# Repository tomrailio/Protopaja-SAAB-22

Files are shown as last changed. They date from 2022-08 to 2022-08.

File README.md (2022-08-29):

# Protocamp-22 / SAAB handheld microwave transmitter.
Protopaja (Protocamp) is a 10 ECTS summerproject course in the University of Aalto to create 
functional interactive prototypes based on briefs by partnering companies. 
The School of Electrical Engineering is the organizational unit and the 
Teachers in charge: Salu Ylirisku and Kimmo Silvonen (kimmo.silvonen@aalto.fi)

SAAB recently developed the passive 'Sirius Compact' radar system for warfare. Now SAAB wants 
to develop a tool to test the limits and potential of the system. The Sirius Compact sensor 
network has been developed specifically with Electronic Warfare (EW) in mind. Modular as 
well as scalable, Sirius Compact's primary use case is seen as providing tactical-level 
situational awareness for warfare from battlefields by generating electromagnetic activity 
imaging with its sensors that detect electromagnetic radiation. In addition to this, Sirius 
Compact is also capable of predicting, classifying and prioritising radar and data link 
signals in the environment. SAAB needs a test tool for the radar system. The purpose of 
this project work is to create the desired test tool. 

The software will be published under a very permissive MIT license. See the licence file 
disclosed in this repository for further details.

# Schematics, PCB blueprint as well as part lists are located in Schematics folder

Technical Specifications:

  * Power level < 20 dBm EIRP (antenna gain + output power).

  * Frequency is 2.4 GHz.

  * Waveform: Continuous wave (narrow bandwidth).

  * Transmitter will be targeted manually by pointing.

Non-functional requirements:

  * Usability.

  * Reliability.

  * Performance.

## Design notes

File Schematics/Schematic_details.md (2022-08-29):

# This folder contains KiCad schematics and PCB blueprint files for our circuit

Components used for this circuit:
    - Antenna: Linx Technology ANT-W63-WRT-UFL
    - Synthesizer: Analog Devices ADF4350BCPZ-RL7
    - RF Amplifier: Analog Devices HMC589AST89E
    - Oscillator: Wurth Elektronik 831024807 (10 Mhz, used as Synthesizer reference)
    - Microcontroler: Atmega328P DIP-28N with a suitable 16Mhz crystal oscillator
    - Regulator: onsemi / Fairchild MC78L05ACP (5V output)
    - Regulator: Texas Instruments LP2992AIM5-3.3/NOPB (3.3V output)
    - Battery: LiPo battery with XT60 connector and voltage of 7.4V

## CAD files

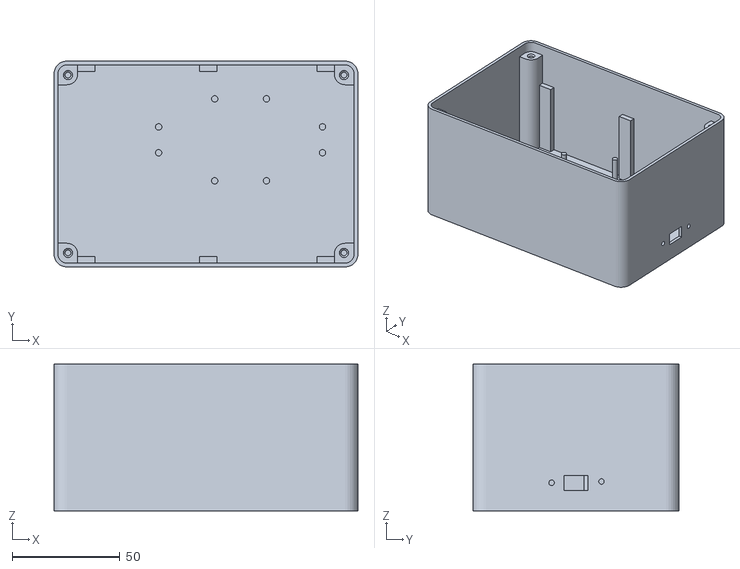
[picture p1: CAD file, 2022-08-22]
3D models/Case.stl
141.0 x 95.5 x 68.0

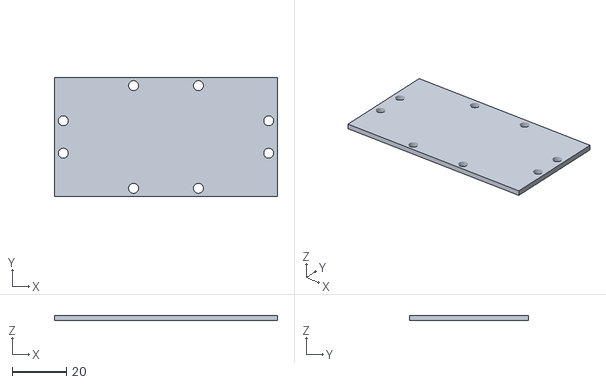
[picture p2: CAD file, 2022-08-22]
3D models/Battery_lid.stl
82.5 x 44.0 x 2.00

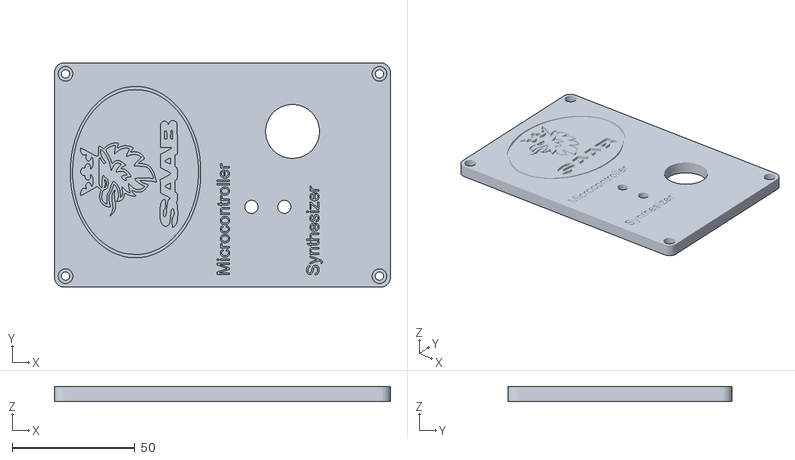
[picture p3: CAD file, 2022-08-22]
3D models/Lid.stl
137.0 x 91.5 x 6.00

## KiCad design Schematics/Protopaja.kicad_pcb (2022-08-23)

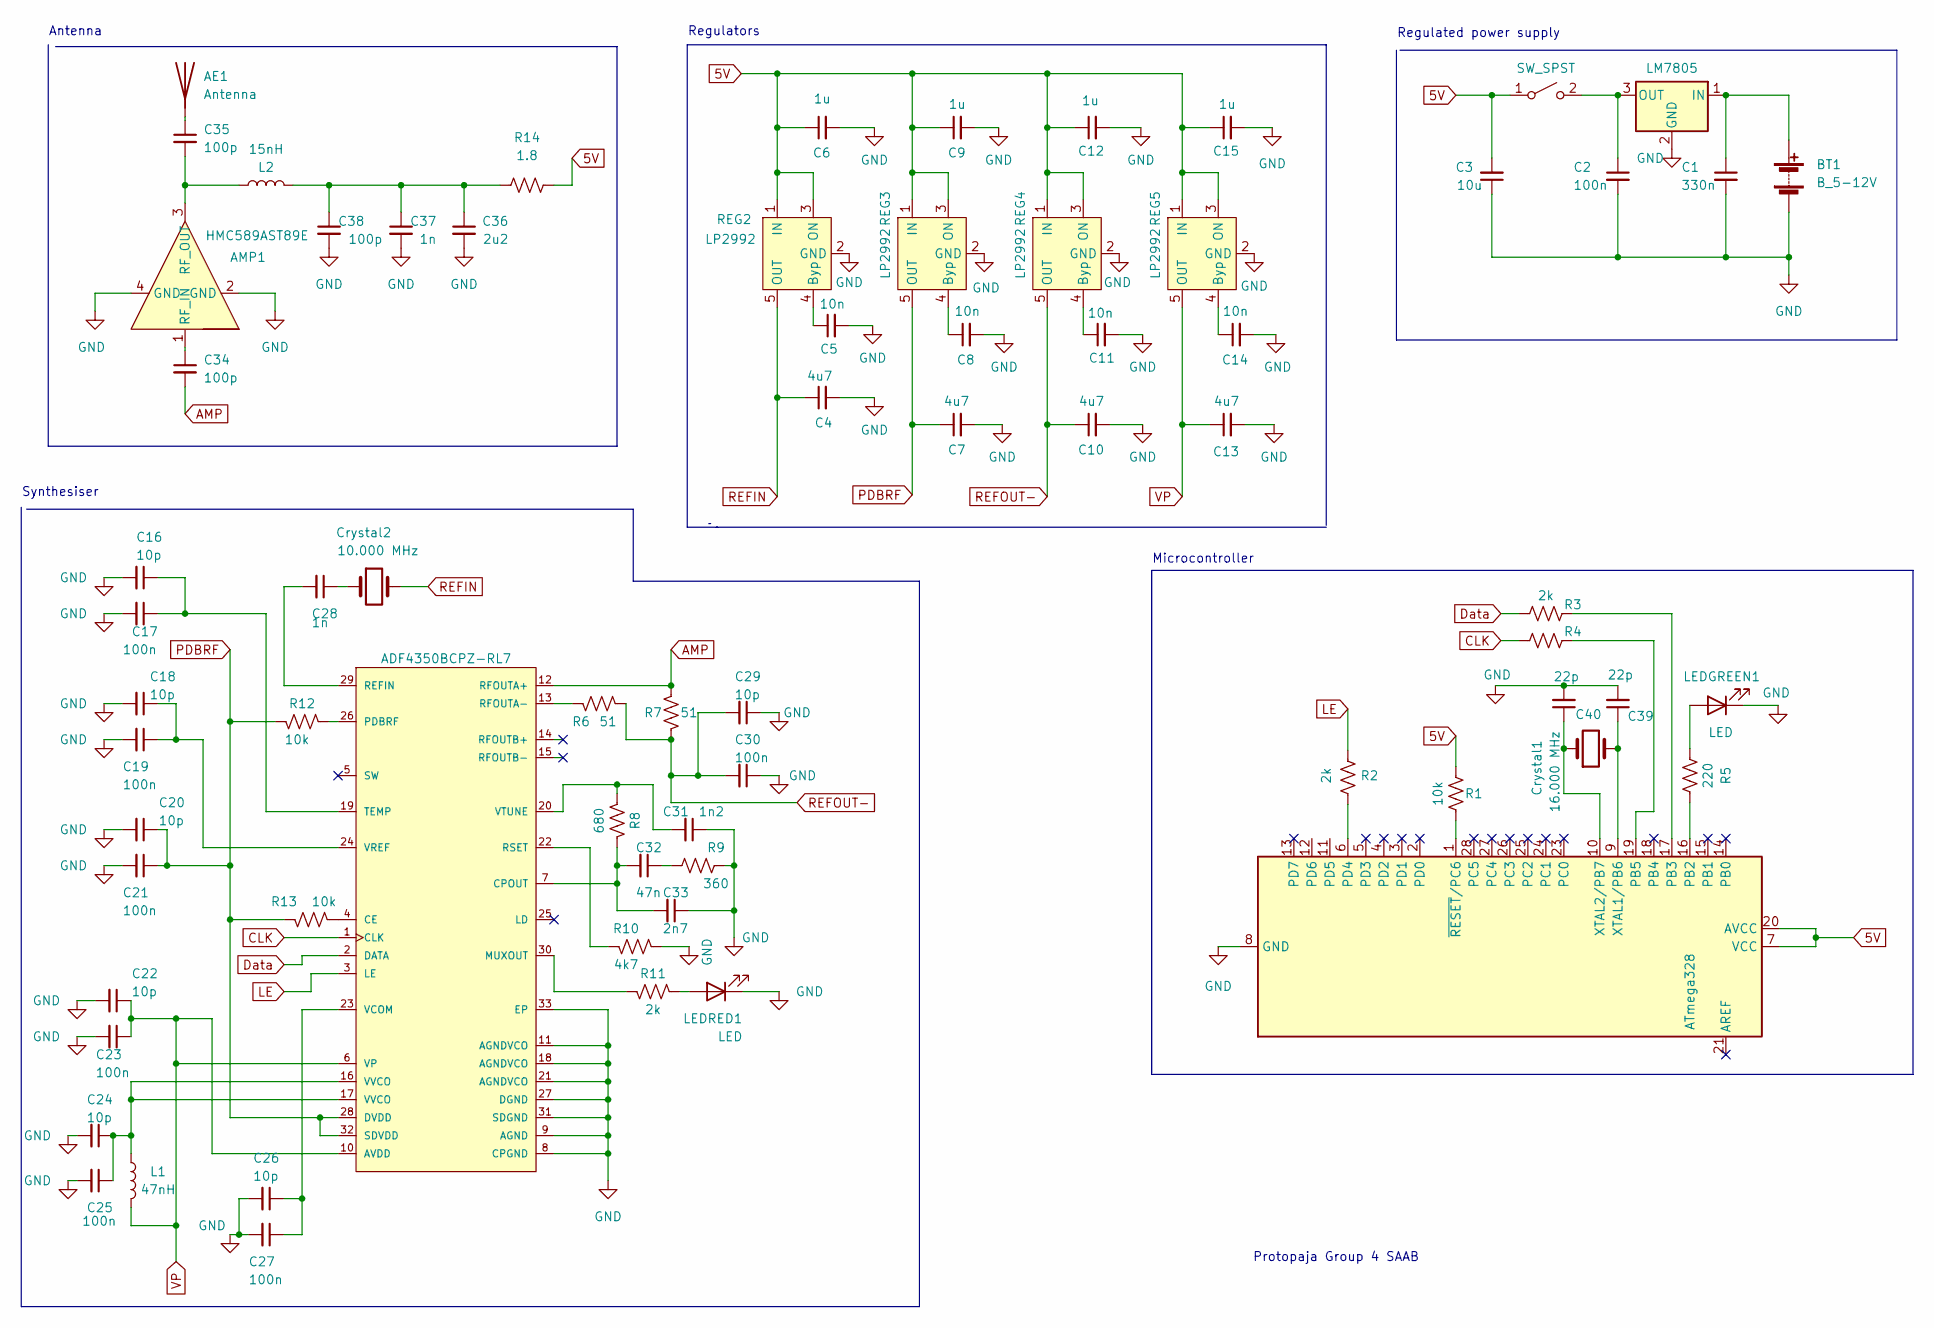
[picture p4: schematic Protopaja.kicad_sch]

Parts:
ADF4350BCPZ-RL7: ADF4350BCPZ-RL7; LFCSP-32-1EP_5x5mm_P0.5mm_EP3.25x3.25mm
AE1: Antenna; U.FL_Molex_MCRF_73412-0110_Vertical
AMP1: HMC589AST89E; HMC
ATmega328: ATmega328-P; DIP-28_W7.62mm
BT1: B_5-12V; AMASS_XT60-F_1x02_P7.20mm_Vertical
C1: 330n; C_0603_1608Metric
C2, C17, C19, C21, C23, C25, C27, C30: 100n; C_0603_1608Metric
C3: 10u; C_0805_2012Metric
C4, C7, C10, C13: 4u7; C_0805_2012Metric
C5, C8, C11, C14: 10n; C_0603_1608Metric
C6, C9, C12, C15: 1u; C_0603_1608Metric
C16, C18, C20, C22, C24, C26, C29: 10p; C_0603_1608Metric
C28: 1n; C_0603_1608Metric
C31: 1n2; C_0603_1608Metric
C32: 47n; C_0603_1608Metric
C33: 2n7; C_0201_0603Metric
C34, C35: 100p; C_0603_1608Metric
C36: 2u2; C_0805_2012Metric
C37: 1n; C_0805_2012Metric
C38: 100p; C_0805_2012Metric
C39, C40: 22p; C_0603_1608Metric
Crystal1: 16.000 MHz; Crystal_HC18-U_Vertical
Crystal2: 10.000 MHz; CFPS
L1: 47nH; L_0402_1005Metric
L2: 15nH; L_0402_1005Metric
LEDGREEN1: LED; LED_D2.0mm_W4.8mm_H2.5mm_FlatTop
LEDRED1: LED; LED_D2.0mm_W4.8mm_H2.5mm_FlatTop
LM7805: L7805; SolderWire-0.5sqmm_1x03_P4.8mm_D0.9mm_OD2.3mm
R1, R12, R13: 10k; R_0603_1608Metric_Pad0.98x0.95mm_HandSolder
R2, R3, R4, R11: 2k; R_0603_1608Metric_Pad0.98x0.95mm_HandSolder
R5: 220; R_0603_1608Metric_Pad0.98x0.95mm_HandSolder
R6, R7: 51; R_0603_1608Metric_Pad0.98x0.95mm_HandSolder
R8: 680; R_0603_1608Metric_Pad0.98x0.95mm_HandSolder
R9: 360; R_0603_1608Metric_Pad0.98x0.95mm_HandSolder
R10: 4k7; R_0603_1608Metric_Pad0.98x0.95mm_HandSolder
R14: 1.8; R_0603_1608Metric
REG2, REG3, REG4, REG5: LP2992
SW2: SW_SPST; SolderWire-0.5sqmm_1x02_P4.6mm_D0.9mm_OD2.1mm

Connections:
5V: ATmega328.7 (VCC), ATmega328.20 (AVCC), C3.2, C6.1, C9.1, C12.1, C15.1, R1.2, R14.2, REG2.1 (IN), REG2.3 (ON), REG3.1 (IN), REG3.3 (ON), REG4.1 (IN), REG4.3 (ON), REG5.1 (IN), REG5.3 (ON), SW2.1 (A)
AMP: ADF4350BCPZ-RL7.12 (RFOUTA+), C34.2, R7.2
CLK: ADF4350BCPZ-RL7.1 (CLK), R4.1
Data: ADF4350BCPZ-RL7.2 (DATA), R3.1
LE: ADF4350BCPZ-RL7.3 (LE), R2.1
unnamed: ADF4350BCPZ-RL7.4 (CE), R13.2
unnamed: ADF4350BCPZ-RL7.7 (CPOUT), C32.2, C33.2, R8.1
unnamed: ADF4350BCPZ-RL7.13 (RFOUTA-), R6.1
unnamed: ADF4350BCPZ-RL7.16 (VVCO), ADF4350BCPZ-RL7.17 (VVCO), C24.1, C25.1, L1.1
unnamed: ADF4350BCPZ-RL7.19 (TEMP), C16.1, C17.1
unnamed: ADF4350BCPZ-RL7.20 (VTUNE), C31.2, R8.2
unnamed: ADF4350BCPZ-RL7.22 (RSET), R10.1
unnamed: ADF4350BCPZ-RL7.23 (VCOM), C26.1, C27.1
unnamed: ADF4350BCPZ-RL7.24 (VREF), C18.1, C19.1
unnamed: ADF4350BCPZ-RL7.26 (PDBRF), R12.2
unnamed: ADF4350BCPZ-RL7.29 (REFIN), C28.2
unnamed: ADF4350BCPZ-RL7.30 (MUXOUT), R11.1
unnamed: AE1.1 (A), C35.1
unnamed: AMP1.1 (RF_IN), C34.1
unnamed: AMP1.3 (RF_OUT), C35.2, L2.1
unnamed: ATmega328.1 (~RESET/PC6), R1.1
unnamed: ATmega328.6 (PD4), R2.2
unnamed: ATmega328.9 (XTAL1/PB6), C39.1, Crystal1.2
unnamed: ATmega328.10 (XTAL2/PB7), C40.1, Crystal1.1
unnamed: ATmega328.16 (PB2), R5.2
unnamed: ATmega328.17 (PB3), R3.2
unnamed: ATmega328.19 (PB5), R4.2
unnamed: BT1.1 (+), C1.1, LM7805.1 (IN)
unnamed: C2.1, LM7805.3 (OUT), SW2.2 (B)
unnamed: C5.1, REG2.4 (Byp)
unnamed: C8.1, REG3.4 (Byp)
unnamed: C11.1, REG4.4 (Byp)
unnamed: C14.1, REG5.4 (Byp)
unnamed: C32.1, R9.1
unnamed: C36.1, C37.1, C38.1, L2.2, R14.1
unnamed: LEDGREEN1.2 (A), R5.1
unnamed: LEDRED1.2 (A), R11.2
PDBRF: ADF4350BCPZ-RL7.28 (DVDD), ADF4350BCPZ-RL7.32 (SDVDD), C7.1, C20.1, C21.1, R12.1, R13.1, REG3.5 (OUT)
REFOUT-: C10.1, C29.2, C30.2, R6.2, R7.1, REG4.5 (OUT)
VP: ADF4350BCPZ-RL7.6 (VP), ADF4350BCPZ-RL7.10 (AVDD), C13.1, C22.1, C23.1, L1.2, REG5.5 (OUT)

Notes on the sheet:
Protopaja Group 4 SAAB
Antenna
Microcontroller
Regulators
Synthesiser
Regulated power supply

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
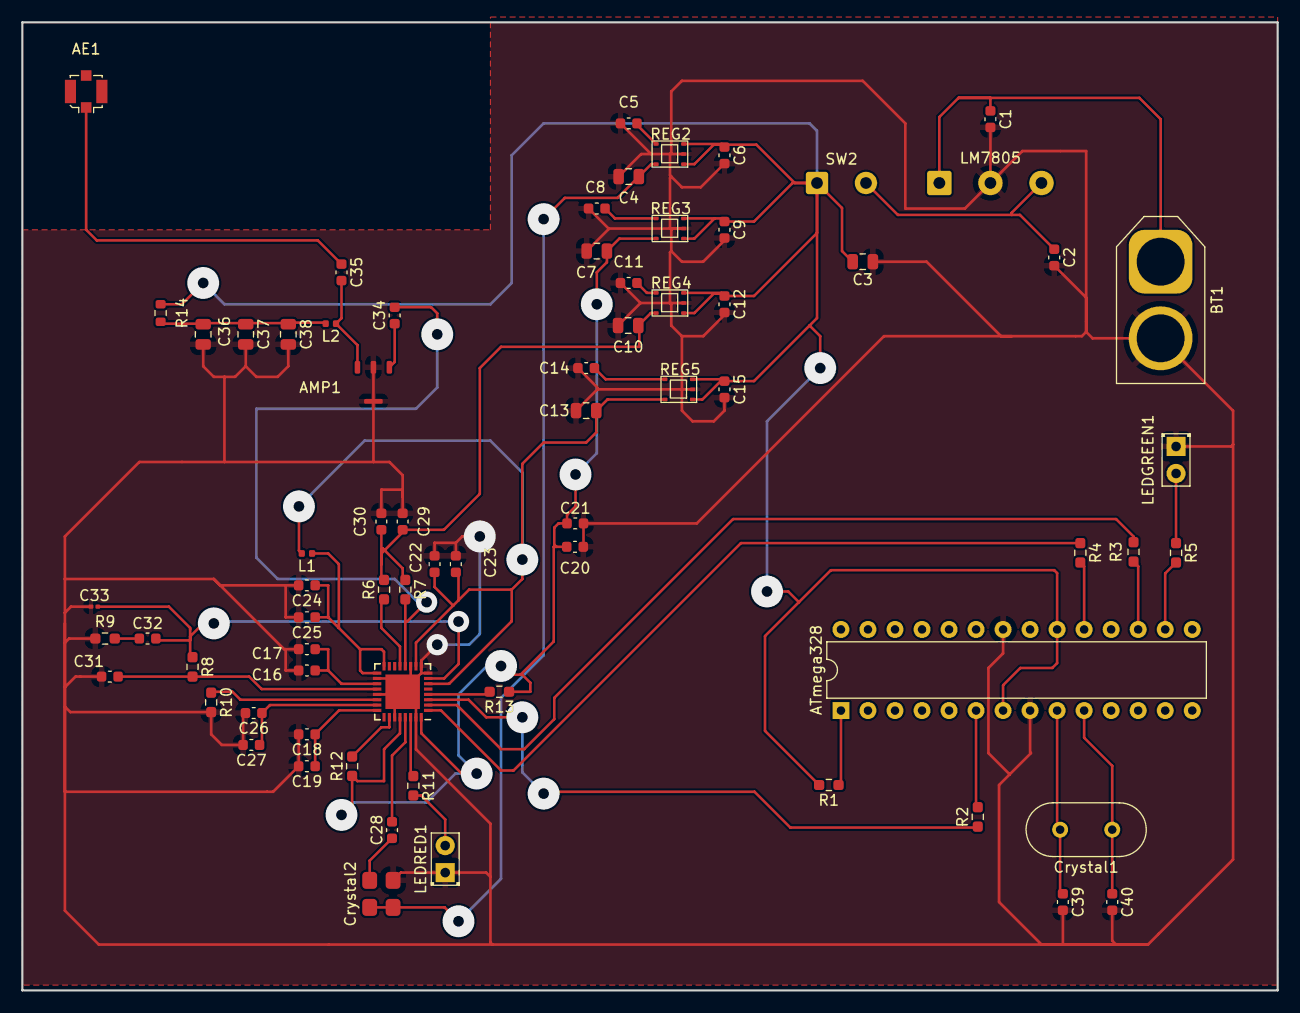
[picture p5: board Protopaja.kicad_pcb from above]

Board: 2 copper layers, 118.0 x 91.0 mm, 71 parts (0 on the bottom side), 43 nets.

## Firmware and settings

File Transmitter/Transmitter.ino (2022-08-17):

#define LE_PIN 4
#define DATA_PIN 11
#define CLK_PIN 13

/* Synthesizer register value, calculated with ADF4350 evaluation board software
   On RF Settings:
       Output frequency: 2400 Mhz
       Reference frequency: 10 Mhz
       
   On Register 4:
       RF output power: -4dbm
       
   Leave all other fields unchanged
*/
#define REGISTER_5 0x580005U
#define REGISTER_4 0x850024U
#define REGISTER_3 0x4B3U
#define REGISTER_2 0x4E42U
#define REGISTER_1 0x8008011U
#define REGISTER_0 0x780000U

#define GREEN_LED 10
// #define BUTTON 2


#define DELAY 1

// Set up basic pins: LE, CLK, DATA for synthesizer,
// GREEN_LED indicates that the microcontroller is active
void setup_ports() {
  pinMode(LE_PIN, OUTPUT);
  digitalWrite(LE_PIN, HIGH);

  pinMode(CLK_PIN, OUTPUT);
  pinMode(DATA_PIN, OUTPUT);

  // Turn on the green LED when the device is powered
  pinMode(GREEN_LED, OUTPUT);
  digitalWrite(GREEN_LED, HIGH);
  
  //pinMode(BUTTON, INPUT);

  digitalWrite(CLK_PIN, LOW);
  digitalWrite(DATA_PIN, LOW);
}

// Write binary data to synthesizer registers
void write_register(unsigned long value) {
  digitalWrite(LE_PIN, LOW);
  delayMicroseconds(DELAY);
  for (int i=31; i >= 0; i--) {                    
    if ((value >> i) & 1)
      digitalWrite(DATA_PIN, HIGH);
    else
      digitalWrite(DATA_PIN, LOW);
    delayMicroseconds(DELAY);
    digitalWrite(CLK_PIN, HIGH);
    delayMicroseconds(DELAY);
    digitalWrite(CLK_PIN, LOW);
    delayMicroseconds(DELAY);
  }
  digitalWrite(DATA_PIN, LOW);
  digitalWrite(LE_PIN, HIGH);
  delayMicroseconds(DELAY);
}

void setup() {
  setup_ports();
  delay(1000);
  
  // Programming the synthesizer output level and other functions
  write_register(REGISTER_5);
  write_register(REGISTER_4);
  write_register(REGISTER_3);
  write_register(REGISTER_2);
  write_register(REGISTER_1);
  write_register(REGISTER_0);
}

void loop() {
}

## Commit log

2022-06-27 Create Library used: Button
2022-07-18 Added example code for the device, created directory for past code snippets and notes
2022-08-12 Update prototype code.ino
2022-08-12 Create Prototype source code
2022-08-12 Update Prototype source code
2022-08-22 Added 3d models for the case
    [Battery_lid.stl, Case.stl, Lid.stl]
2022-08-22 changed arduino file name
2022-08-23 Moved schematics to Schematics folder and added parts name and information in Schematics/Schematic details
    [Protopaja.kicad_pcb, Protopaja.kicad_sch]
2022-08-23 Added battery detail to Schematic details file
2022-08-29 Added additional instrucitoons in README file
    [Protopaja.kicad_pcb, Protopaja.kicad_sch]
